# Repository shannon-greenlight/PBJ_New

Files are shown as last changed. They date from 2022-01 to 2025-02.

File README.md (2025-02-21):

# PBJ_New
# This project has been replaced by PBJ_EU_3.

PBJ Project (Proto Board with Jacks) -- For Synthesizer hardware development

https://www.greenfacelabs.com/pbj-eu/

This project provides the KiCAD files used to fab PBJ synthesizer development breadboards.
It requires the KiCAD libraries found at: https://github.com/shannon-greenlight/KiCAD

It also requires the Digi-Key footprint and symbol libraries available at: https://www.digikey.com/en/resources/design-tools/kicad

Add these paths to the symbol libraries:

dk_Sockets-for-ICs-Transistors	.../KiCAD/digikey-symbols/dk_Sockets-for-ICs-Transistors.lib		

dk_Rectangular-Connectors-Headers-Male-Pins	.../KiCAD/digikey-symbols/dk_Rectangular-Connectors-Headers-Male-Pins.lib		

dk_Pushbutton-Switches	.../KiCAD/digikey-symbols/dk_Pushbutton-Switches.lib

greenface-symbols	...\KiCAD\greenface-symbols.lib		

Add these paths to the footprint libraries:

digikey-footprints	.../KiCAD/digikey-footprints.pretty		

panel	...\KiCAD\panel.pretty		

sputterizer	...\KiCAD\sputterizer.pretty		

The Excel file pbj_eu.xlsx can be uploaded directly to Digi-Key to order parts.

Currently, only the PBJ EU is available. But a standalone version, the PBJ Solo, is in the wings.

Note: If you don't have KiCAD and just want to make the PBJ, you can send the Gerber files to fab and use the Excel file to buy the parts. 
The jpegs of the EU in use (EU_inuse.jpg) and of the schematic (PBJ_EU/pbj_eu.jpg) can be used for reference.

PBJ EU Features

800 point solderless proto board

4 switched 3.5mm jacks

Wiring connector interfaces jacks and power to proto board

LED monitors for each jack. Red indicates positive voltage present. Blue indicates negative.

Test point per jack gives convenient access for scope/meter probes.

2 Large Ground connection points are excellent for attaching alligator clips

2 MULT switches connect jack 1 to 2 or jack 3 to 4.

Tip and Switch signals are routed from the jacks to the wiring connector.

+/- 12V and +5V power are routed to the wiring connector.

Power is switched.

Power indicator shows presence of +5V.

10 pin EU power output connector can be used to power off-rack modules.

22 HP wide

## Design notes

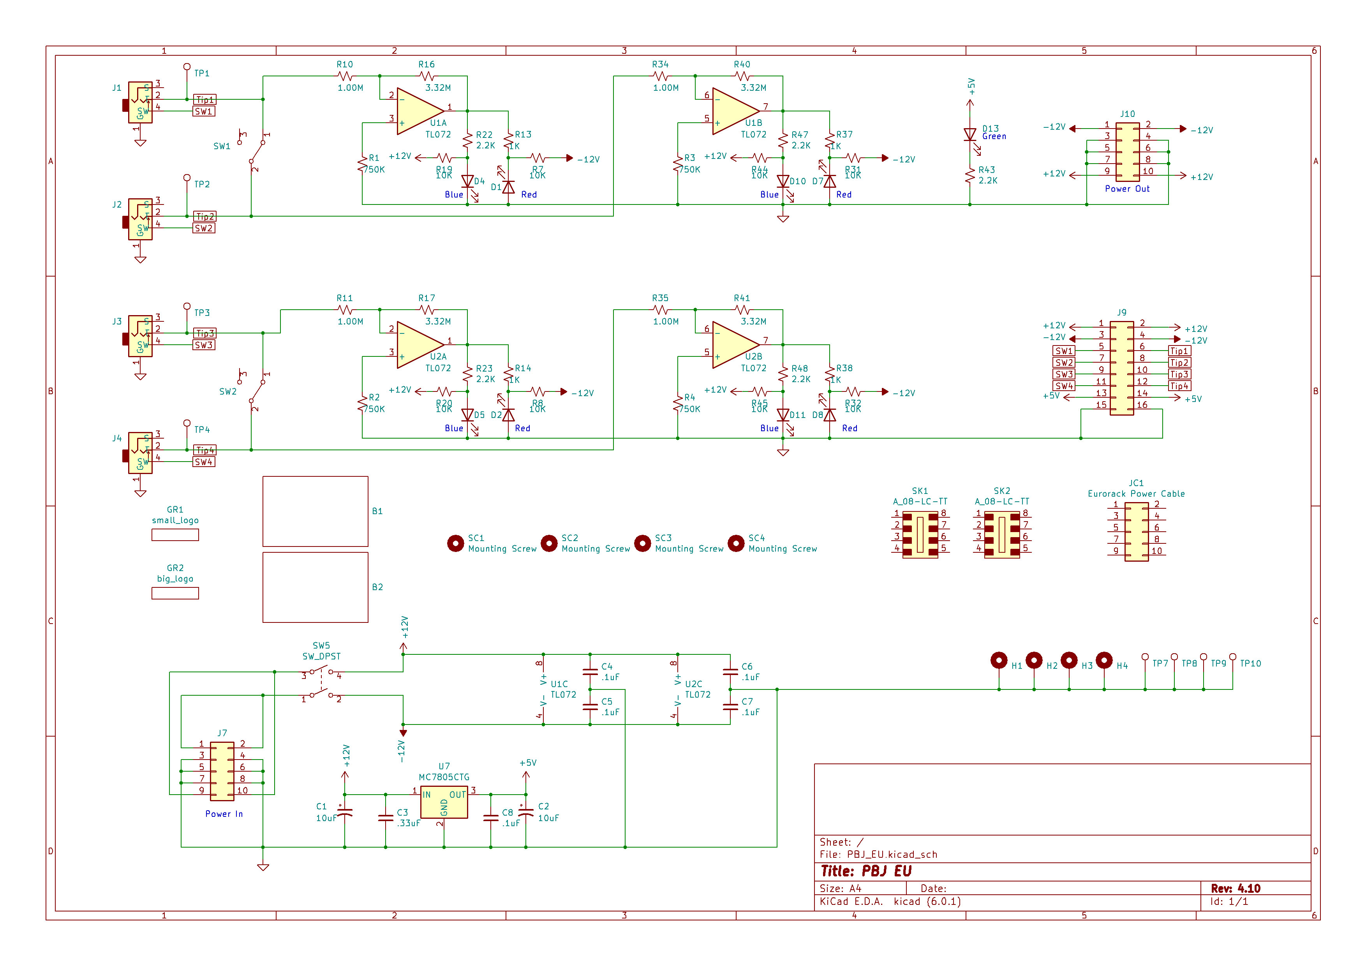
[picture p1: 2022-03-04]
PBJ_EU/pbj_eu.jpg

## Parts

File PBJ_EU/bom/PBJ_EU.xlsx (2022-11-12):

Reference | Quantity | Value | Digi-Key Part
B1 B2 | 2 | Breadboard_400 | 1286-1185-ND
C1 C4 C5 C12 | 4 | 10uF | 478-7366-1-ND
C2 C8 | 2 | .33uF | 445-180638-1-ND
C3 C6 C7 C9 C10 C11 | 6 | .1uF | 478-3188-ND
D1 D3 D5 D7 | 4 | RED LED | 732-5005-ND
D2 D4 D6 D8 | 4 | BLUE LED | 732-11401-ND
D9 | 1 | GREEN LED | 732-5008-ND
J1 J2 J3 J4 | 4 | Molex_47257 | WM17366-ND
J5 J7 | 2 | Conn_02x05_Odd_Even | S2011EC-05-ND
J6 | 1 | Conn_02x08_Odd_Even_Female | S7111-ND
JC1 | 1 | Eurorack Power Cable | H3CCS-1018G-ND
R1 R2 R3 R4 | 4 | 1K | CF14JT1K00CT-ND
R5 | 1 | 2.2K | CF14JT2K20CT-ND
SC1 SC2 SC3 SC4 | 4 | Mounting Screw | 335-1156-ND
SK1 SK2 | 2 | A_08-LC-TT | AE9986-ND
SW1 SW2 | 2 | SW_SPDT | CKN10397-ND
SW3 | 1 | SW_DPST | CKN9891-ND
TP1 TP2 TP3 TP4 TP5 TP6 TP7 TP8 | 8 | TestPoint | 36-5006-ND
U1 U2 | 2 | TL072 | 296-14997-5-ND
U3 | 1 | MC7805CTG | MC7805CTGOS-ND
U4 | 1 | MIC29150-3.3WT | 576-1104-ND

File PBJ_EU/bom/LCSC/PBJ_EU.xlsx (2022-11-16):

Reference | Quantity | Value | Footprint | LCSC Part #
C1 C5 | 2 | 10uF | Capacitor_THT:CP_Radial_D5.0mm_P2.00mm | C88726
C13 C14 C15 C16 | 4 | 10nF | Capacitor_THT:C_Rect_L7.0mm_W2.0mm_P5.00mm | C1710
C2 C6 C7 C8 C10 C11 | 6 | .1uF | Capacitor_THT:C_Rect_L7.0mm_W2.0mm_P5.00mm | C84772
C4 C12 | 2 | 22uF | Capacitor_THT:CP_Radial_D5.0mm_P2.00mm | C43346
D18 D19 D20 D21 | 4 | SB120 | Diode_THT:D_DO-41_SOD81_P7.62mm_Horizontal | C174003
J5 J7 | 2 | Conn_02x05_Odd_Even | Connector_PinHeader_2.54mm:PinHeader_2x05_P2.54mm_Vertical | C492422
R1 R2 R3 R4 R5 R6 R7 R8 R9 R14 R15 R16 | 12 | 2.2K | Resistor_THT:R_Axial_DIN0207_L6.3mm_D2.5mm_P10.16mm_Horizontal | C120063
R10 R11 R12 R13 | 4 | 1M | Resistor_THT:R_Axial_DIN0207_L6.3mm_D2.5mm_P10.16mm_Horizontal | C433776
R17 R18 | 2 | 620 | Resistor_THT:R_Axial_DIN0207_L6.3mm_D2.5mm_P10.16mm_Horizontal | C713992
RV1 RV2 | 2 | 5K | Potentiometer_THT:Potentiometer_Bourns_3296W_Vertical | C60620
SK1 SK2 | 2 | A_08-LC-TT | Package_DIP:DIP-8_W7.62mm_Socket_LongPads | C72124
TP1 TP2 TP3 TP4 TP5 TP6 TP7 TP8 | 8 | TestPoint | TestPoint:TestPoint_Keystone_5005-5009_Compact | C238123
U1 U2 | 2 | TL072 | Package_DIP:DIP-8_W7.62mm_Socket_LongPads | C72124
U3 U4 | 2 | LM317_TO-220 | Package_TO_SOT_THT:TO-220-3_Vertical | C14502

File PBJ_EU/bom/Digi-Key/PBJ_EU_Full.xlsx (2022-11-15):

Reference | Quantity | Value | Digi-Key Part | Other
B1 B2 | 2 | Breadboard_400 | 1286-1185-ND
C1 C5 | 2 | 10uF | P124234CT-ND
C13 C14 C15 C16 | 4 | 10nF | BC2662CT-ND
C2 C6 C7 C8 C10 C11 | 6 | .1uF | 478-3188-ND
C4 C12 | 2 | 22uF | P15374CT-ND
D18 D19 D20 D21 | 4 | SB120 | 112-SB120-E3/54CT-ND
J1 J2 J3 J4 | 4 | Molex_47257 | WM17366-ND
J5 J7 | 2 | Conn_02x05_Odd_Even | S2011EC-05-ND
J6 | 1 | Conn_02x08_Odd_Even_Female | S7111-ND
JC1 | 1 | Eurorack Power Cable | H3CCS-1018G-ND
R1 R2 R3 R4 R5 R6 R7 R8 R9 R14 R15 R16 | 12 | 2.2K | CF14JT2K20CT-ND
R10 R11 R12 R13 | 4 | 1M | CF14JT1M00CT-ND
R17 R18 | 2 | 620 | S620CACT-ND
RV1 RV2 | 2 | 5K | 3296W-502LF-ND
SC1 SC2 SC3 SC4 | 4 | Mounting Screw | 335-1156-ND
SK1 SK2 | 2 | A_08-LC-TT | AE9986-ND
SW1 SW2 SW4 | 3 | SW_SPDT | CKN10397-ND
SW3 | 1 | SW_DPST | CKN9891-ND
TP1 TP2 TP3 TP4 TP5 TP6 TP7 TP8 | 8 | TestPoint | 36-5006-ND
U1 U2 | 2 | TL072 | 296-1775-5-ND
U3 U4 | 2 | LM317_TO-220 | 497-19621-ND

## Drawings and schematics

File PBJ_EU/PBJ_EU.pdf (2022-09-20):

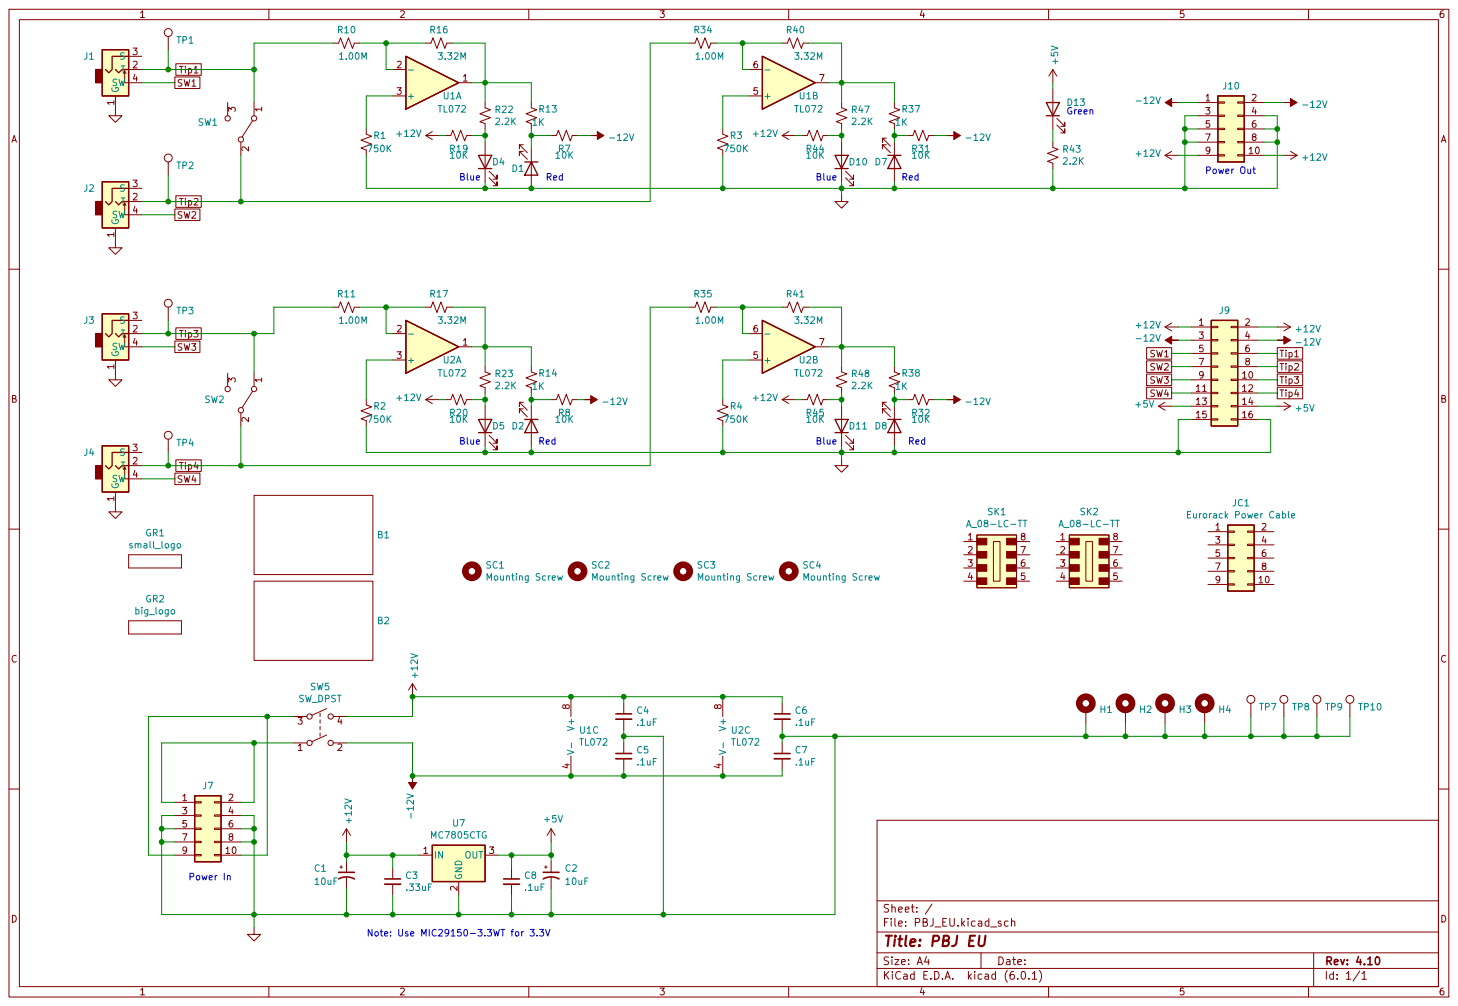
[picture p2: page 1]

Blue Blue Note: Use MIC29150-3.3WT for 3.3V

Id: 1/1 Title: PBJ EU

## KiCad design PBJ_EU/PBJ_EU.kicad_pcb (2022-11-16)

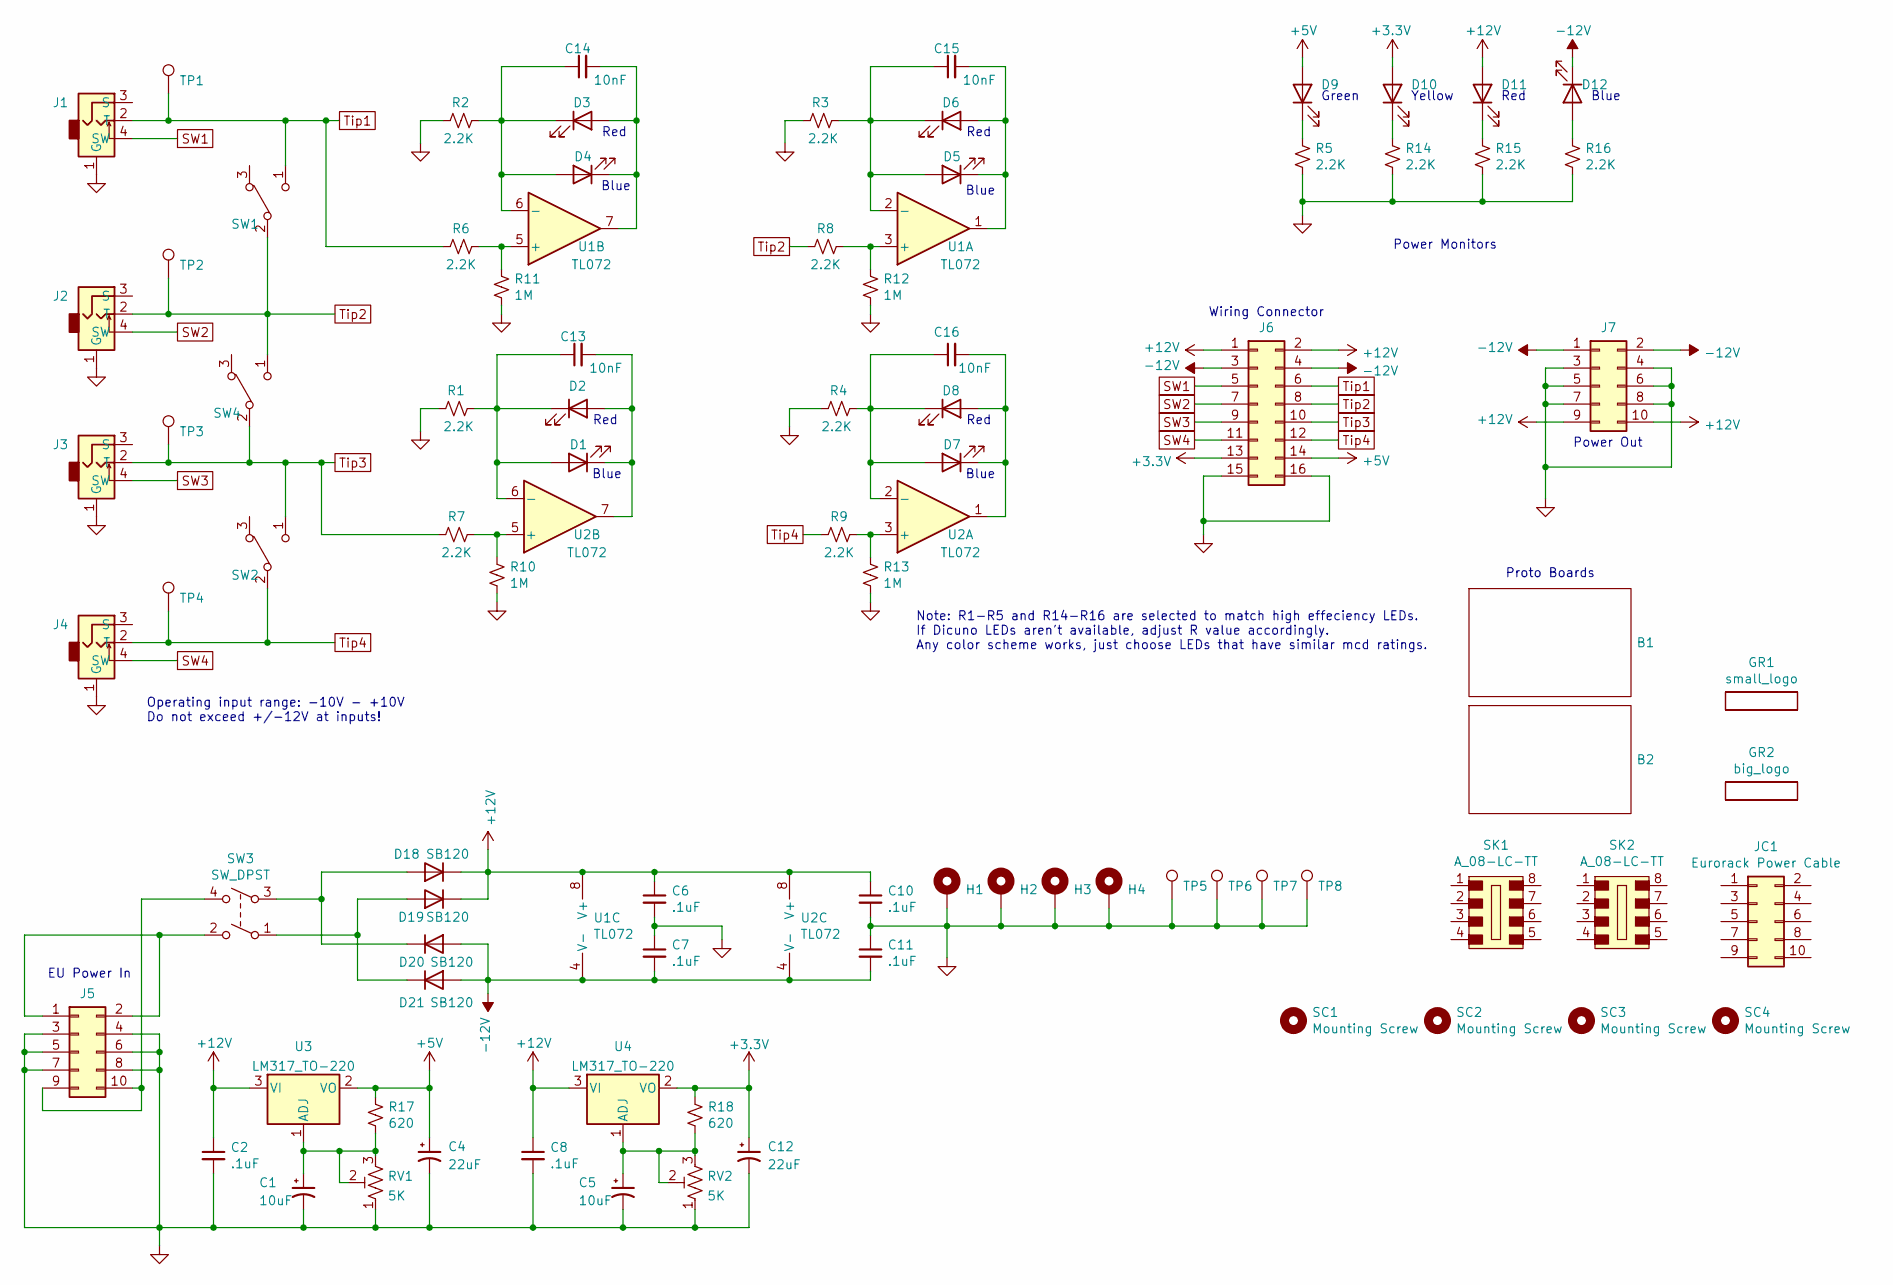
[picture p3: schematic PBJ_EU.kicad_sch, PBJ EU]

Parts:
B1, B2: Breadboard_400; Proto_400; Digi-Key Part 1286-1185-ND
C1, C5: 10uF; CP_Radial_D5.0mm_P2.00mm; Digi-Key Part P124234CT-ND
C2, C6, C7, C8, C10, C11: .1uF; C_Rect_L7.0mm_W2.0mm_P5.00mm; Digi-Key Part 478-3188-ND
C4, C12: 22uF; CP_Radial_D5.0mm_P2.00mm; Digi-Key Part P15374CT-ND
C13, C14, C15, C16: 10nF; C_Rect_L7.0mm_W2.0mm_P5.00mm; Digi-Key Part BC2662CT-ND
D1, D4, D5, D7, D12: BLUE LED; LED_D3.0mm
D2, D3, D6, D8, D11: RED LED; LED_D3.0mm
D9: GREEN LED; LED_D3.0mm
D10: YELLOW LED; LED_D3.0mm
D18, D19, D20, D21: SB120; D_DO-41_SOD81_P7.62mm_Horizontal; Digi-Key Part 112-SB120-E3/54CT-ND
GR1: small_logo; small_face
GR2: big_logo; logo_black
H1, H2, H3, H4: MountingHole_Pad; MountingHole_3.2mm_M3_SmPad
J1, J2, J3, J4: Molex_47257; Molex-0472570001; Digi-Key Part WM17366-ND
J5, J7: Conn_02x05_Odd_Even; PinHeader_2x05_P2.54mm_Vertical; Digi-Key Part S2011EC-05-ND
J6: Conn_02x08_Odd_Even_Female; PinHeader_2x08_P2.54mm_Vertical; Digi-Key Part S7111-ND
JC1: Eurorack Power Cable; Digi-Key Part H3CCS-1018G-ND
R1, R2, R3, R4, R5, R6, R7, R8, R9, R14, R15, R16: 2.2K; R_Axial_DIN0207_L6.3mm_D2.5mm_P10.16mm_Horizontal; Digi-Key Part CF14JT2K20CT-ND
R10, R11, R12, R13: 1M; R_Axial_DIN0207_L6.3mm_D2.5mm_P10.16mm_Horizontal; Digi-Key Part CF14JT1M00CT-ND
R17, R18: 620; R_Axial_DIN0207_L6.3mm_D2.5mm_P10.16mm_Horizontal; Digi-Key Part S620CACT-ND
RV1, RV2: 5K; Potentiometer_Bourns_3296W_Vertical; Digi-Key Part 3296W-502LF-ND
SC1, SC2, SC3, SC4: Mounting Screw; Digi-Key Part 335-1156-ND
SK1, SK2: A_08-LC-TT; DIP-8_W7.62mm_Socket_LongPads; Digi-Key Part AE9986-ND
SW1, SW2, SW4: SW_SPDT; SW_Slide_1P2T_CK_OS102011MS2Q; Digi-Key Part CKN10397-ND
SW3: SW_DPST; S202031MS02Q; Digi-Key Part CKN9891-ND
TP1, TP2, TP3, TP4: TestPoint; TestPoint_Keystone_5005-5009_Compact; Digi-Key Part 36-5006-ND
TP5, TP6, TP7, TP8: TestPoint; TestPoint_Keystone_5005-5009_Compact
U1, U2: TL072; DIP-8_W7.62mm_Socket_LongPads; Digi-Key Part 296-1775-5-ND
U3, U4: LM317_TO-220; TO-220-3_Vertical; Digi-Key Part 497-19621-ND

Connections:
+3V3: C12.1, D10.2 (A), J6.13, R18.1, U4.2 (VO)
+5V: C4.1, D9.2 (A), J6.14, R17.1, U3.2 (VO)
+12V: C2.1, C6.1, C8.1, C10.1, D11.2 (A), D18.1 (K), D19.1 (K), J6.1, J6.2, J7.9, J7.10, U1.8 (V+), U2.8 (V+), U3.3 (VI), U4.3 (VI)
-12V: C7.2, C11.2, D12.1 (K), D20.2 (A), D21.2 (A), J6.3, J6.4, J7.1, J7.2, U1.4 (V-), U2.4 (V-)
GND: C1.2, C2.2, C4.2, C5.2, C6.2, C7.1, C8.2, C10.2, C11.1, C12.2, H1.1, H2.1, H3.1, H4.1, J1.1 (G), J2.1 (G), J3.1 (G), J4.1 (G), J5.3, J5.4, J5.5, J5.6, J5.7, J5.8, J6.15, J6.16, J7.3, J7.4, J7.5, J7.6, J7.7, J7.8, R1.1, R2.1, R3.1, R4.1, R5.2, R10.2, R11.2, R12.2, R13.2, R14.2, R15.2, R16.2, RV1.1, RV2.1, TP5.1, TP6.1, TP7.1, TP8.1
unnamed: C1.1, R17.2, RV1.2, RV1.3, U3.1 (ADJ)
unnamed: C5.1, R18.2, RV2.2, RV2.3, U4.1 (ADJ)
unnamed: C13.1, D1.2 (A), D2.1 (K), R1.2, U2.6 (-)
unnamed: C13.2, D1.1 (K), D2.2 (A), U2.7
unnamed: C14.1, D3.1 (K), D4.2 (A), R2.2, U1.6 (-)
unnamed: C14.2, D3.2 (A), D4.1 (K), U1.7
unnamed: C15.1, D5.2 (A), D6.1 (K), R3.2, U1.2 (-)
unnamed: C15.2, D5.1 (K), D6.2 (A), U1.1
unnamed: C16.1, D7.2 (A), D8.1 (K), R4.2, U2.2 (-)
unnamed: C16.2, D7.1 (K), D8.2 (A), U2.1
unnamed: D9.1 (K), R5.1
unnamed: D10.1 (K), R14.1
unnamed: D11.1 (K), R15.1
unnamed: D12.2 (A), R16.1
unnamed: D18.2 (A), D20.1 (K), SW3.3
unnamed: D19.2 (A), D21.1 (K), SW3.1
unnamed: J5.1, J5.2, SW3.2
unnamed: J5.9, J5.10, SW3.4
unnamed: R7.1, R10.1, U2.5 (+)
unnamed: R6.1, R11.1, U1.5 (+)
unnamed: R8.1, R12.1, U1.3 (+)
unnamed: R9.1, R13.1, U2.3 (+)
SW1: J1.4 (SW), J6.5
SW2: J2.4 (SW), J6.7
SW3: J3.4 (SW), J6.9
SW4: J4.4 (SW), J6.11
Tip1: J1.2 (T), J6.6, R6.2, SW1.1 (A), TP1.1
Tip2: J2.2 (T), J6.8, R8.2, SW1.2 (B), SW4.1 (A), TP2.1
Tip3: J3.2 (T), J6.10, R7.2, SW2.1 (A), SW4.2 (B), TP3.1
Tip4: J4.2 (T), J6.12, R9.2, SW2.2 (B), TP4.1

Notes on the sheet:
EU Power In
Blue
Proto Boards
Red
Wiring Connector
Yellow
Power Monitors
Operating input range: -10V - +10V Do not exceed +/-12V at inputs!
Note: R1-R5 and R14-R16 are selected to match high effeciency LEDs. If Dicuno LEDs aren't available, adjust R value accordingly. Any color scheme works, just choose LEDs that have similar mcd ratings.
Power Out
Green

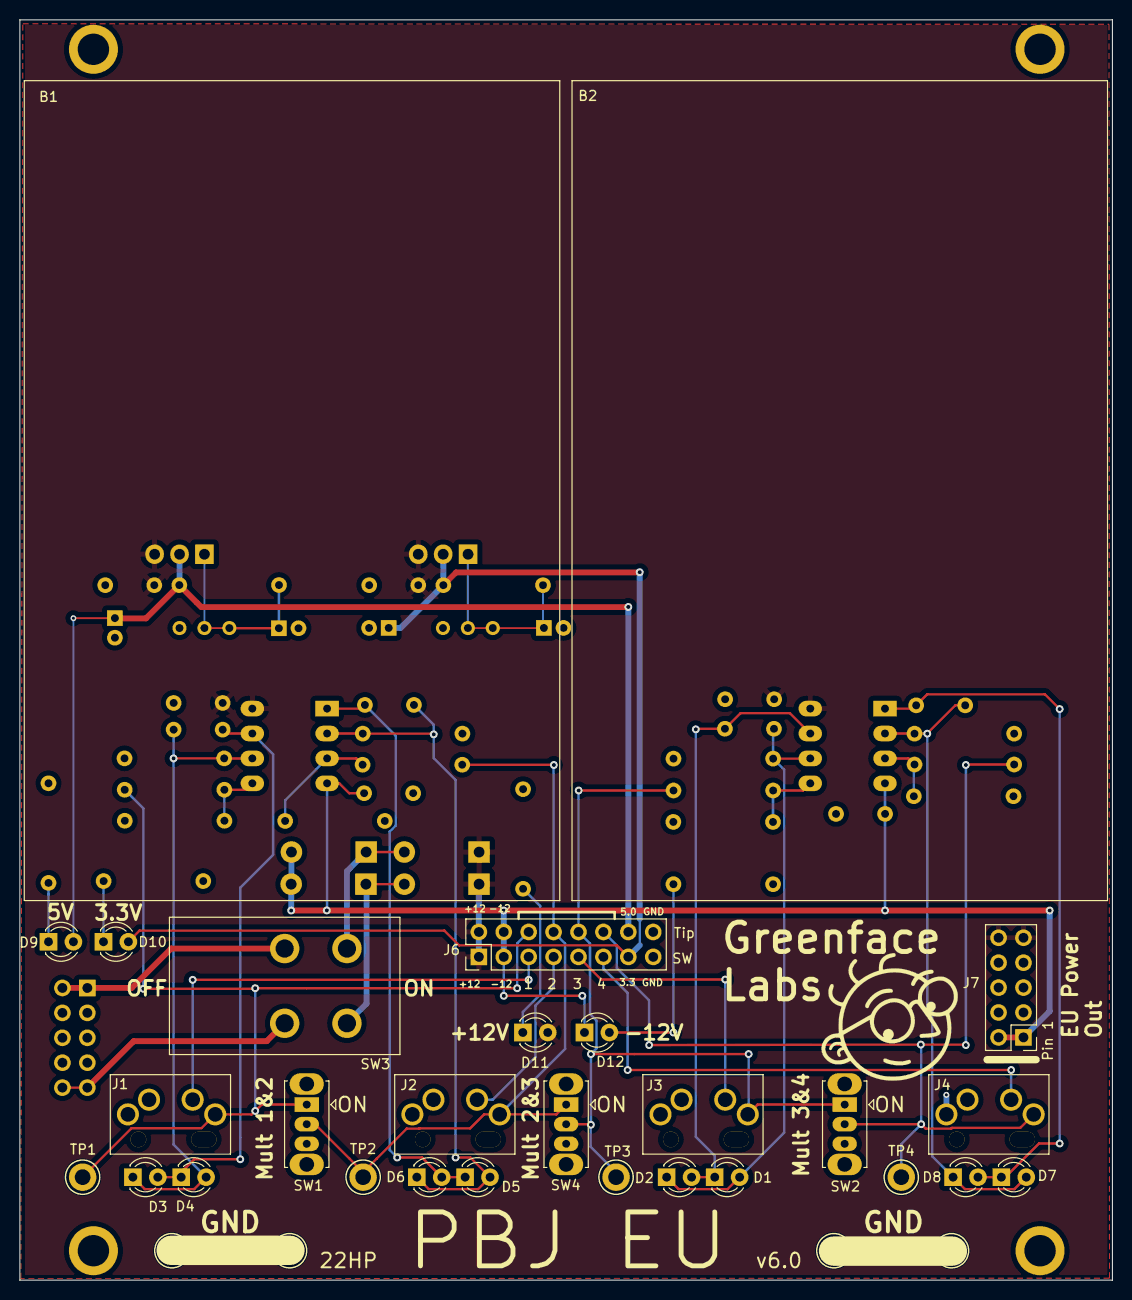
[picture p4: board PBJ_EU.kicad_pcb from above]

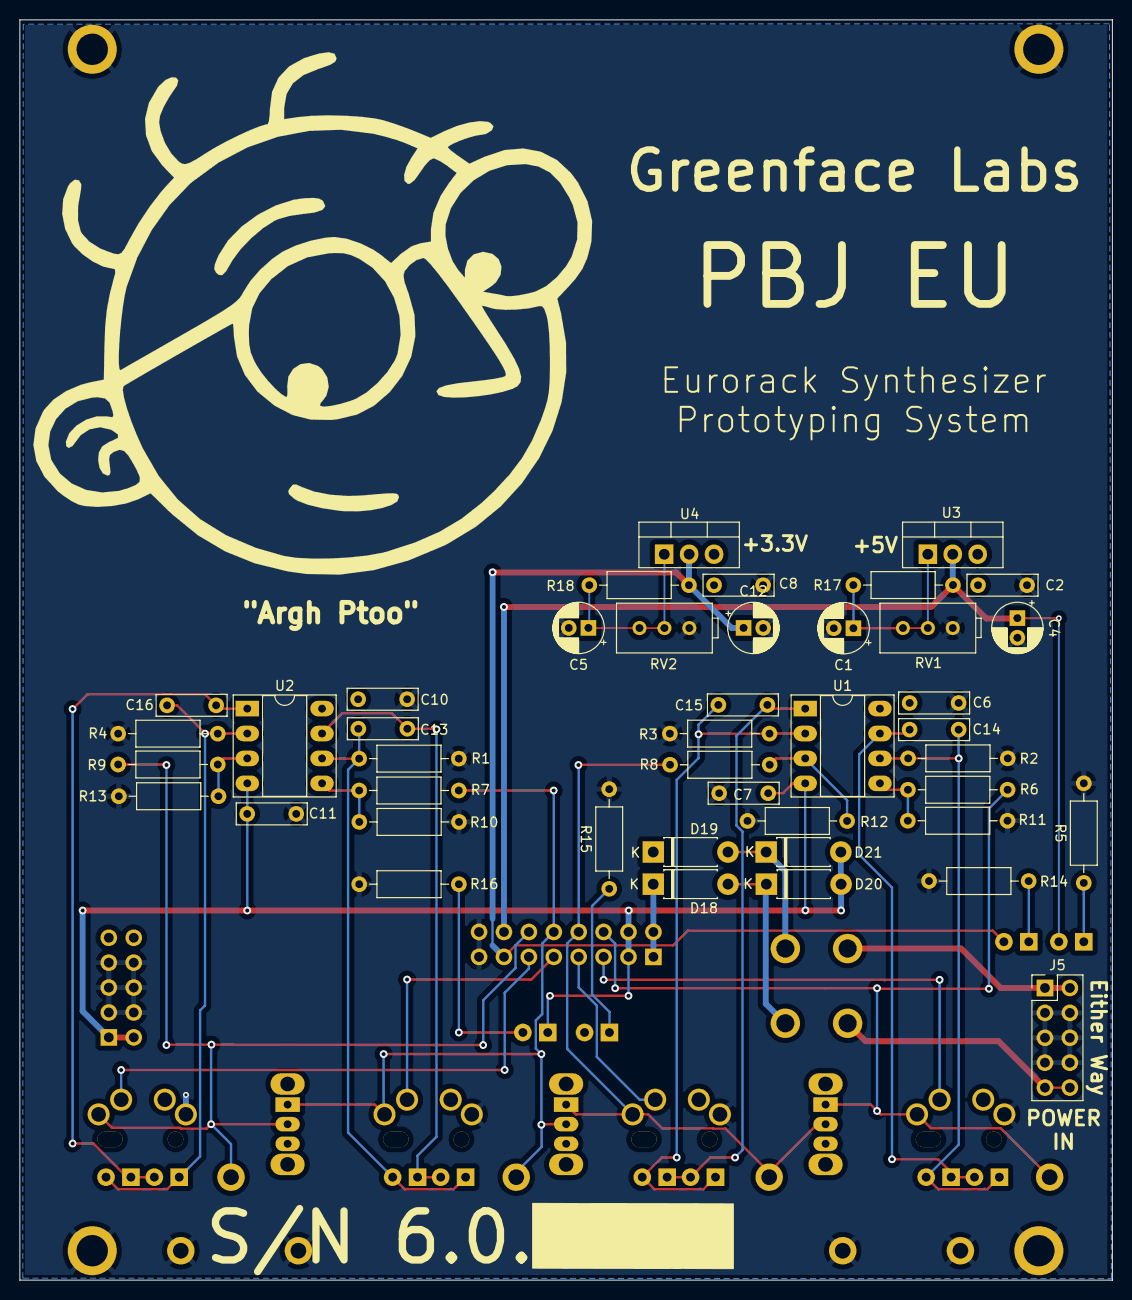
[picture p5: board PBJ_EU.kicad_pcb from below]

Board: 2 copper layers, 111.4 x 128.5 mm, 81 parts (44 on the bottom side), 35 nets.

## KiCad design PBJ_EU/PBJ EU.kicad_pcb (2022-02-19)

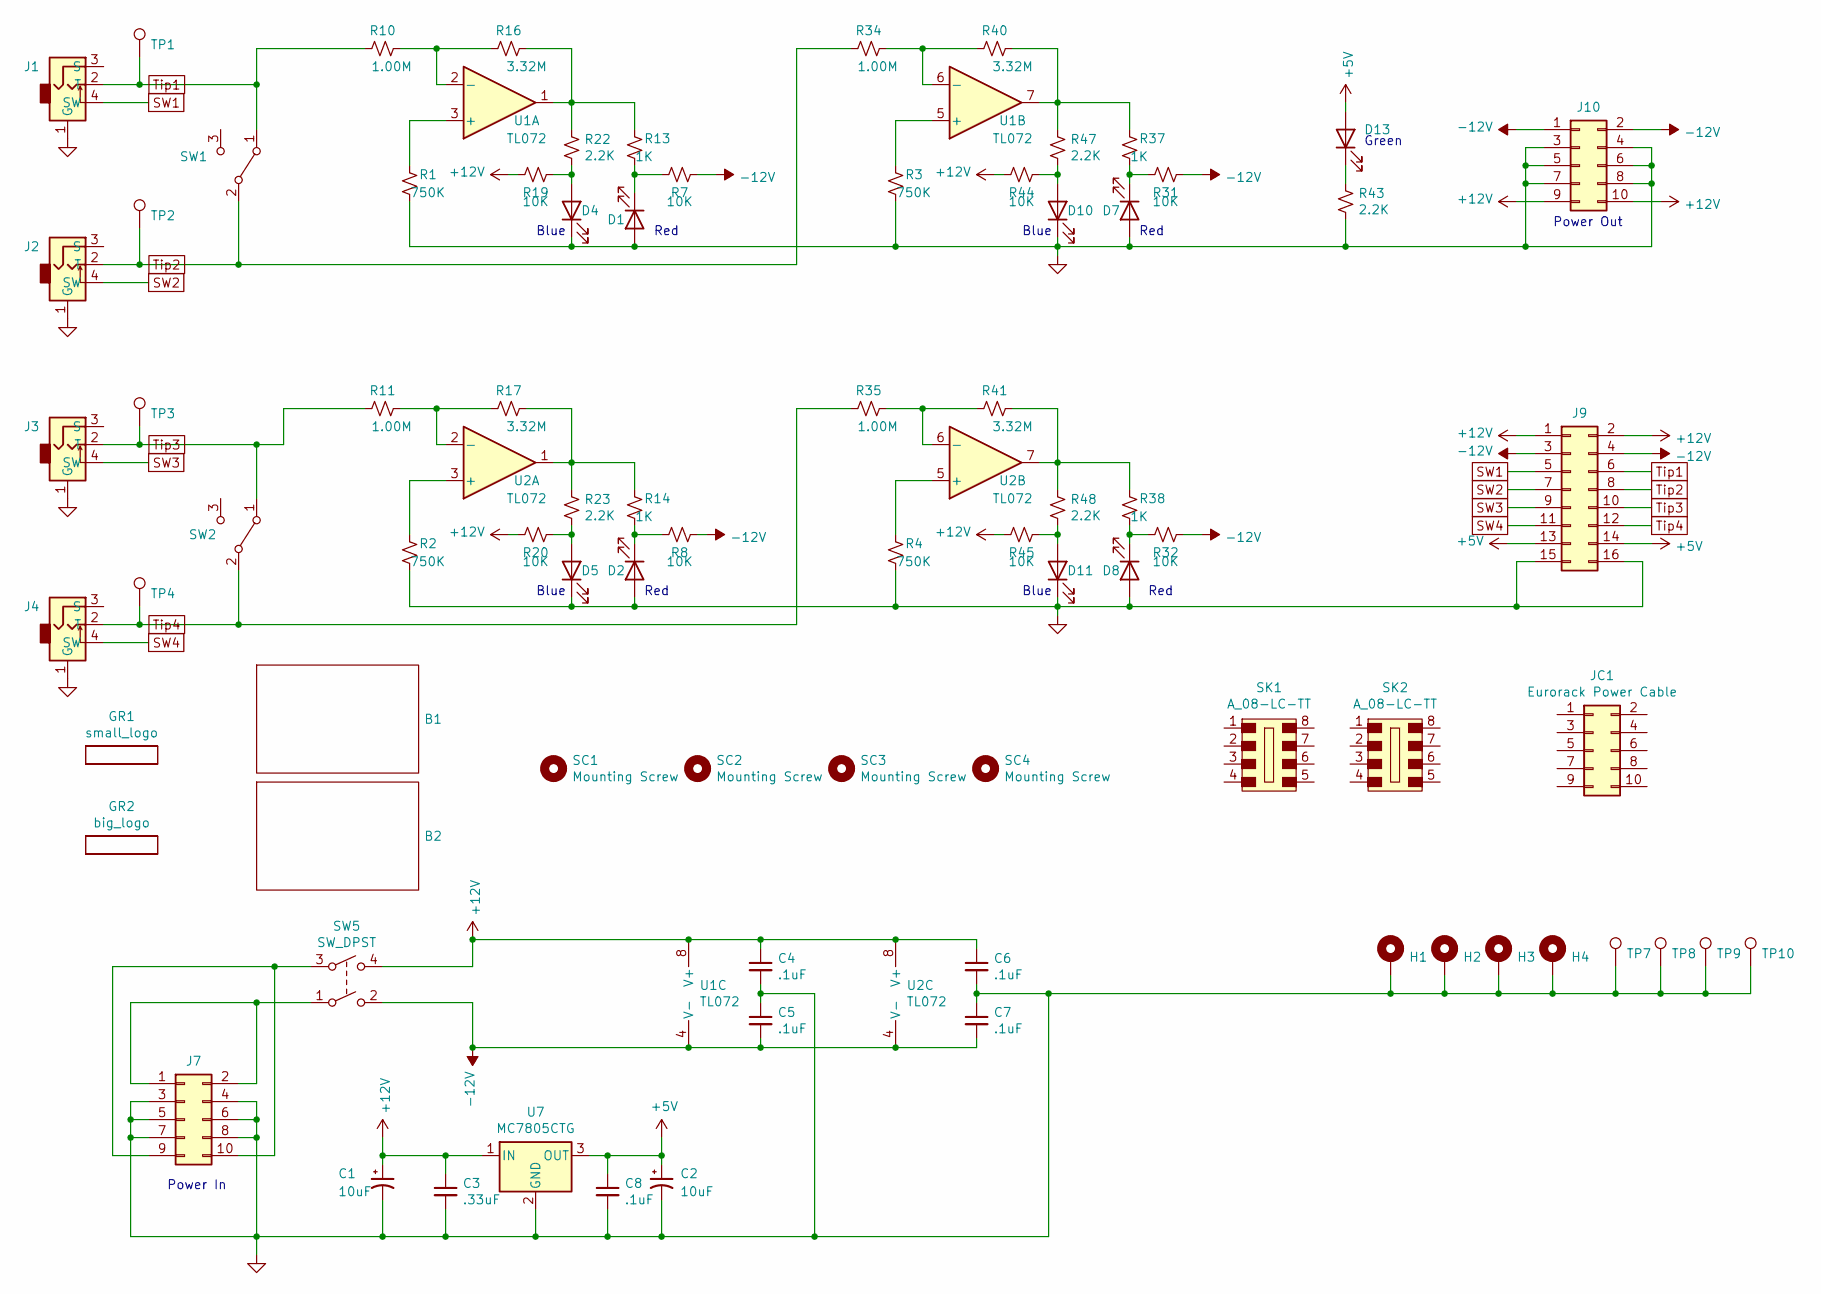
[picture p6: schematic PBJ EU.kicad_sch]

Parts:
B1, B2: Breadboard_400; Proto_400; Digi-Key Part 1286-1185-ND
C1, C2: 10uF; CP_Radial_Tantal_D5.0mm_P5.00mm; Digi-Key Part 478-7366-1-ND
C3: .33uF; C_Rect_L7.0mm_W2.0mm_P5.00mm; Digi-Key Part 445-180638-1-ND
C4, C5, C6, C7, C8: .1uF; C_Rect_L7.0mm_W2.0mm_P5.00mm; Digi-Key Part 478-3188-ND
D1, D2, D7, D8: RED LED; LED_D3.0mm; Digi-Key Part 732-5005-ND
D4, D5, D10, D11: BLUE LED; LED_D3.0mm; Digi-Key Part 732-11401-ND
D13: GREEN LED; LED_D3.0mm; Digi-Key Part 732-5008-ND
GR1: small_logo; small_face
GR2: big_logo; logo_black
H1, H2, H3, H4: MountingHole_Pad; MountingHole_3.2mm_M3_SmPad
J1, J2, J3, J4: Molex_47257; Molex-0472570001; Digi-Key Part WM17366-ND
J7, J10: Conn_02x05_Odd_Even; PinHeader_2x05_P2.54mm_Vertical; Digi-Key Part S2011EC-05-ND
J9: Conn_02x08_Odd_Even_Female; PinHeader_2x08_P2.54mm_Vertical; Digi-Key Part S7111-ND
JC1: Eurorack Power Cable; Digi-Key Part H3CCS-1018G-ND
R1, R2, R3, R4: 750K; R_Axial_DIN0207_L6.3mm_D2.5mm_P10.16mm_Horizontal; Digi-Key Part S750KQCT-ND
R7, R8, R19, R20, R31, R32, R44, R45: 10K; R_Axial_DIN0207_L6.3mm_D2.5mm_P10.16mm_Horizontal; Digi-Key Part CF14JT10K0CT-ND
R10, R11, R34, R35: 1.00M; R_Axial_DIN0207_L6.3mm_D2.5mm_P10.16mm_Horizontal; Digi-Key Part RNF14FTD1M00CT-ND
R13, R14, R37, R38: 1K; R_Axial_DIN0207_L6.3mm_D2.5mm_P10.16mm_Horizontal; Digi-Key Part CF14JT1K00CT-ND
R16, R17, R40, R41: 3.32M; R_Axial_DIN0207_L6.3mm_D2.5mm_P10.16mm_Horizontal; Digi-Key Part RNF14FTD3M32CT-ND
R22, R23, R43, R47, R48: 2.2K; R_Axial_DIN0207_L6.3mm_D2.5mm_P10.16mm_Horizontal; Digi-Key Part CF14JT2K20CT-ND
SC1, SC2, SC3, SC4: Mounting Screw; Digi-Key Part 335-1156-ND
SK1, SK2: A_08-LC-TT; Digi-Key Part AE9986-ND
SW1, SW2: SW_SPDT; SW_Slide_1P2T_CK_OS102011MS2Q; Digi-Key Part CKN10397-ND
SW5: SW_DPST; S202031MS02Q; Digi-Key Part CKN9891-ND
TP1, TP2, TP3, TP4, TP7, TP8, TP9, TP10: TestPoint; TestPoint_Keystone_5005-5009_Compact; Digi-Key Part 36-5006-ND
U1: TL072
U2: TL072; DIP-8_W7.62mm; Digi-Key Part 296-14997-5-ND‎
U7: MC7805CTG; TO-220-3_Vertical; Digi-Key Part MC7805CTGOS-ND

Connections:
+5V: C2.1, C8.1, D13.2 (A), J9.13, J9.14, U7.3 (OUT)
+12V: C1.1, C3.1, C4.1, C6.1, J9.1, J9.2, J10.9, J10.10, R19.1, R20.1, R44.1, R45.1, SW5.4, U1.8 (V+), U2.8 (V+), U7.1 (IN)
-12V: C5.2, C7.2, J9.3, J9.4, J10.1, J10.2, R7.2, R8.2, R31.2, R32.2, SW5.2, U1.4 (V-), U2.4 (V-)
GND: C1.2, C2.2, C3.2, C4.2, C5.1, C6.2, C7.1, C8.2, D1.2 (A), D2.2 (A), D4.1 (K), D5.1 (K), D7.2 (A), D8.2 (A), D10.1 (K), D11.1 (K), H1.1, H2.1, H3.1, H4.1, J1.1 (G), J2.1 (G), J3.1 (G), J4.1 (G), J7.3, J7.4, J7.5, J7.6, J7.7, J7.8, J9.15, J9.16, J10.3, J10.4, J10.5, J10.6, J10.7, J10.8, R1.2, R2.2, R3.2, R4.2, R43.2, TP7.1, TP8.1, TP9.1, TP10.1, U7.2 (GND)
unnamed: D1.1 (K), R7.1, R13.2
unnamed: D2.1 (K), R8.1, R14.2
unnamed: D4.2 (A), R19.2, R22.2
unnamed: D5.2 (A), R20.2, R23.2
unnamed: D7.1 (K), R31.1, R37.2
unnamed: D8.1 (K), R32.1, R38.2
unnamed: D10.2 (A), R44.2, R47.2
unnamed: D11.2 (A), R45.2, R48.2
unnamed: D13.1 (K), R43.1
unnamed: J7.1, J7.2, SW5.1
unnamed: J7.9, J7.10, SW5.3
unnamed: R1.1, U1.3 (+)
unnamed: R2.1, U2.3 (+)
unnamed: R3.1, U1.5 (+)
unnamed: R4.1, U2.5 (+)
unnamed: R10.2, R16.1, U1.2 (-)
unnamed: R11.2, R17.1, U2.2 (-)
unnamed: R13.1, R16.2, R22.1, U1.1
unnamed: R14.1, R17.2, R23.1, U2.1
unnamed: R34.2, R40.1, U1.6 (-)
unnamed: R35.2, R41.1, U2.6 (-)
unnamed: R37.1, R40.2, R47.1, U1.7
unnamed: R38.1, R41.2, R48.1, U2.7
SW1: J1.4 (SW), J9.5
SW2: J2.4 (SW), J9.7
SW3: J3.4 (SW), J9.9
SW4: J4.4 (SW), J9.11
Tip1: J1.2 (T), J9.6, R10.1, SW1.1 (A), TP1.1
Tip2: J2.2 (T), J9.8, R34.1, SW1.2 (B), TP2.1
Tip3: J3.2 (T), J9.10, R11.1, SW2.1 (A), TP3.1
Tip4: J4.2 (T), J9.12, R35.1, SW2.2 (B), TP4.1

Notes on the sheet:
Blue
Power In
Red
Power Out
Green

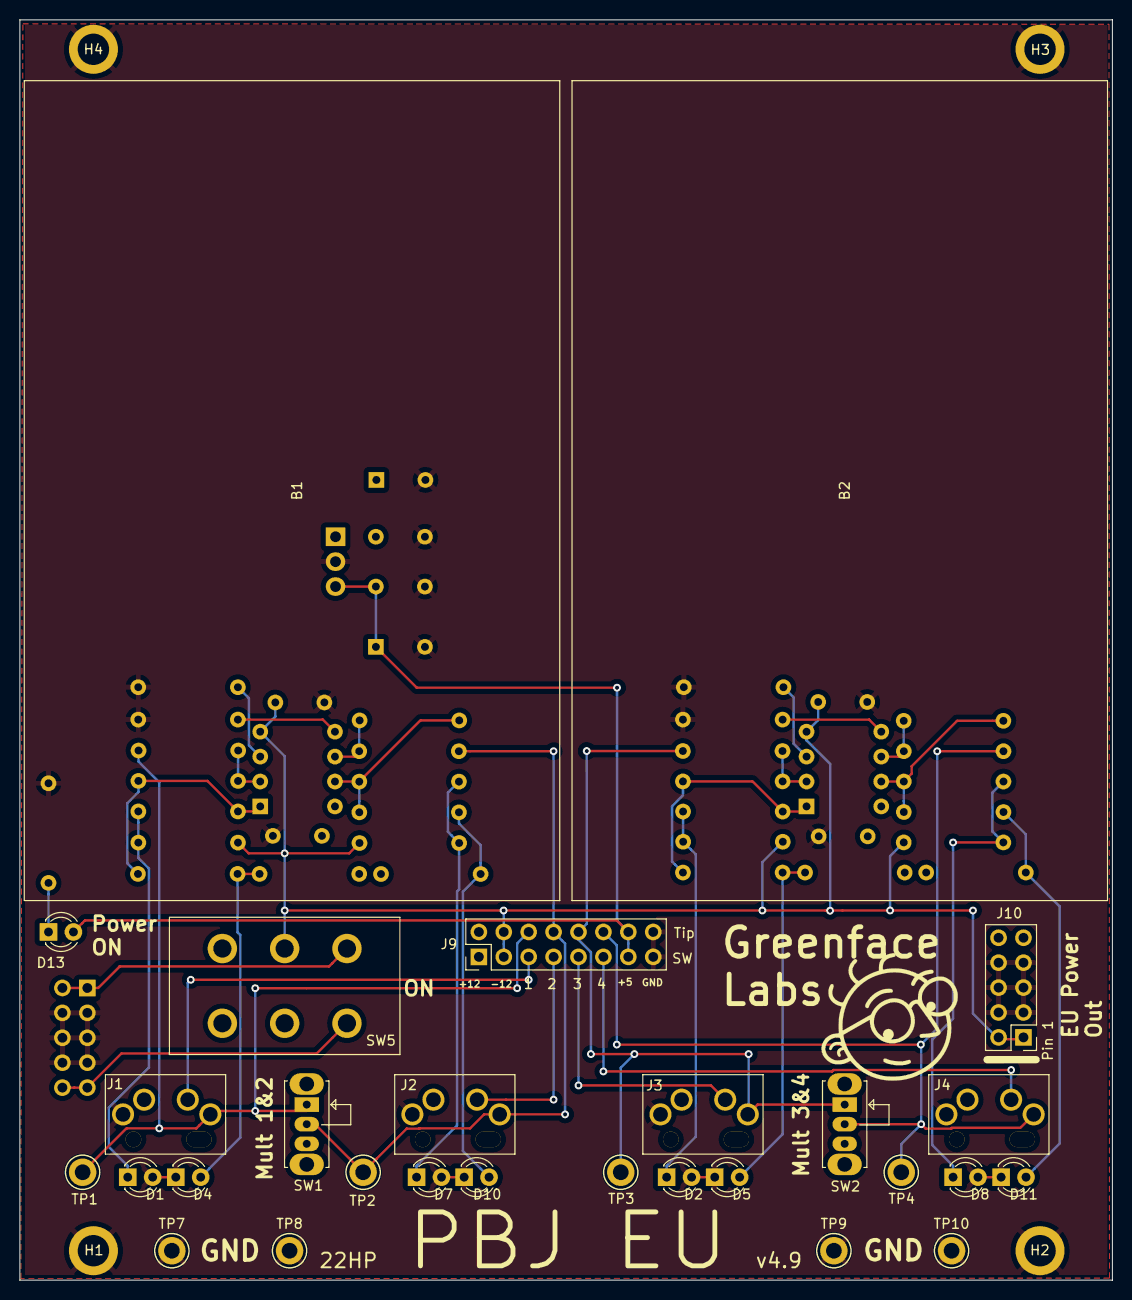
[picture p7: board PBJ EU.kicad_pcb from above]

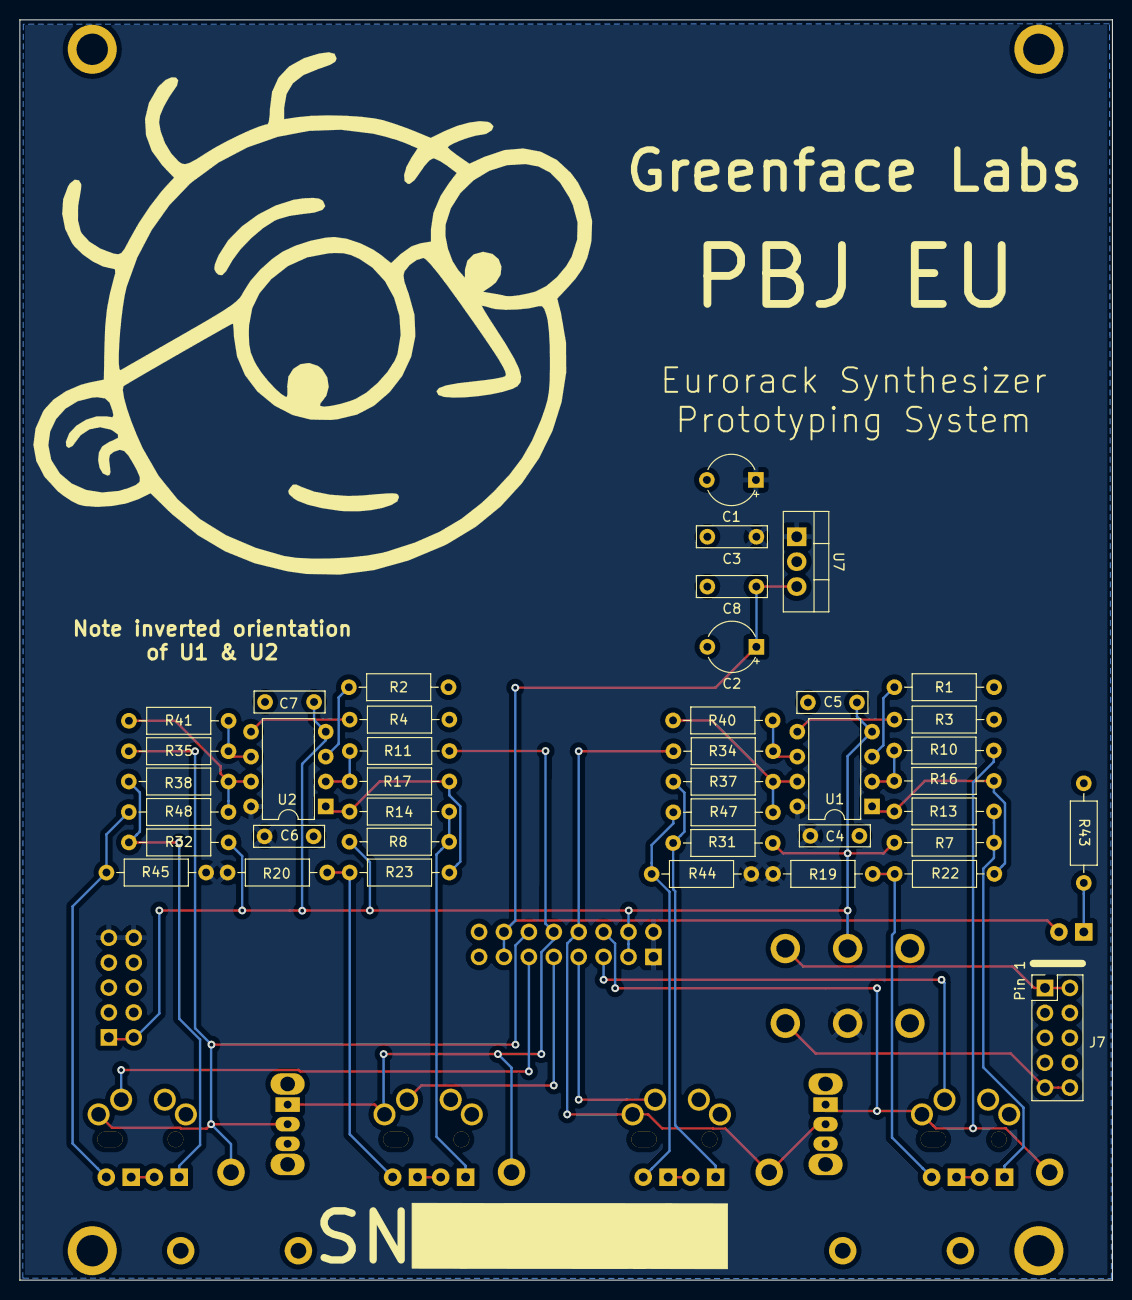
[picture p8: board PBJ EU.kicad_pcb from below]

Board: 2 copper layers, 111.4 x 128.5 mm, 75 parts (42 on the bottom side), 35 nets.

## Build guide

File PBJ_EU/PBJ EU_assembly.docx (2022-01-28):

# PBJ EU Assembly Instructions

The PBJ EU uses components on both sides of the board as well as stacked components to maximize rack space. Because of this, the order of assembly is designed to avoid installing a component that covers the holes of another component.

Because of the density of the circuitry, a conical .8mm tip soldering iron is suggested.

Difficulty: beginner. OK for first build.

1. Install components on back side of the board first. This is most components including op amps, resistors, capacitors and the voltage regulator. Use of sockets for the op amps is recommended.
2. Trim leads so that they are as flush with the front side of the board as possible. This is to avoid shorts to the proto board which is placed on top of this area.
3. Install front-side components. Connectors, jacks LEDs etc.
4. Install proto-boards. They lock together for a tight fit. You can do this before fixing them to the board.
5. That’s all! You’re ready to test.

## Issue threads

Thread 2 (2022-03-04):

Jpegs missing?

rahji, 2022-03-04:
The readme says "The jpegs of the EU in use (EU_inuse.jpg) and of the schematic (PBJ_EU/pbj_eu.jpg) can be used for reference." but I don't see them in the repo. (Thanks for doing this btw - I think every PCB project repo should have images or PDFs of the schematic, PCB, etc and not just EDA/gerber files.

shannon-greenlight, 2022-03-04:
My mistake! I will fix it in the repo. But for now, here is the pdf version.

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

shannon-greenlight, 2022-03-04:
Here’s the jpeg.

Please let me know if you find any other problems.

Thanks!

Shannon

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

rahji, 2022-03-04:
We're the PDF and the JPG supposed to be the same? I thought the JPG was a photo of the board in use. Right now they're both the schematic . Thanks

shannon-greenlight, 2022-03-04:
Hi Rob,

At this point they are supposed to be the same. However, your suggestion is a good one. I will see if I can develop a consistent approach for all of my products.

In the meantime, you can see a picture of the PBJ EU in use on the website.

https://www.greenfacelabs.com/pbj-eu/

Thanks again for your comments. I want everything to be as good as it can be, but things do slip through the cracks. Just too many hats and not enough heads. 😉

Have you been able to get the needed parts?

Best,

Shannon

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

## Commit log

2020-11-12 Init checkin for ver 2.0
    [PBJ EU.kicad_pcb, PBJ EU.sch, PBJ EU_transistor.sch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]
2020-12-08 ver 3.0
    [PBJ EU.kicad_pcb, PBJ EU.sch, pbj_eu.xlsx]
2021-01-26 Removed unused KiCAD files.
    [PBJ EU_transistor.sch]
2021-01-26 Updates spice to match schematic values.
2021-12-25 Fixed rescue libs
    [PBJ EU.kicad_pcb, PBJ EU.sch, PBJ EU_parts.sch]
2021-12-25 Adds jpeg of schematic
2021-12-25 A little formatting of excel file.
    [pbj_eu.xlsx]
2021-12-25 Adds gerber files
    [PBJ EU-B_Cu.gbr, PBJ EU-B_Mask.gbr, PBJ EU-B_Paste.gbr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]
2021-12-25 Updates to ver 4.7.
    [PBJ EU-B_Cu.gbr, PBJ EU-B_Mask.gbr, PBJ EU-B_Paste.gbr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]
2022-01-27 version 4.8
    Fixes power connector.
    [PBJ EU-B_Cu.gbr, PBJ EU-B_Mask.gbr, PBJ EU-B_Paste.gbr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]
2022-01-28 v 4.9
    Adds caps to regulator. Adds graphics and text.
    [PBJ EU-B_Cu.gbr, PBJ EU-B_Mask.gbr, PBJ EU-B_Paste.gbr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]
2022-02-19 Move to KiCAD 6.0
    [PBJ EU-B_Cu.gbr, PBJ EU-B_Mask.gbr, PBJ EU-B_Paste.gbr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]
2022-02-19 Fixed 3d models
    Some 3d models are still unavailable
    [PBJ EU.kicad_pcb]
2022-02-19 Changed name so that BOM would work
    Looks like 6.0 BOM bombs when there is a space in the filename.
    [PBJ_EU-B_Cu.gbr, PBJ_EU-B_Mask.gbr, PBJ_EU-B_Paste.gbr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]
2022-02-19 Adds BOM
    [PBJ_EU.kicad_sch, PBJ_EU.xlsx, pbj_eu.xlsx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]
2022-02-22 Updates footprint 3d shapes
    [PBJ_EU.kicad_pcb]
2022-03-04 Adds pdf of schematic
2022-08-20 Version 4.10
    [PBJ_EU-B_Cu.gbr, PBJ_EU-B_Mask.gbr, PBJ_EU-B_Paste.gbr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]
2022-09-20 Adds note to schematic about 3.3V regulator option
    [PBJ_EU.kicad_sch, PBJ_EU.xlsx]
2022-11-12 v5.2
    Adds LCSC build support. Fixes to monitor circuitry.
    [PBJ_EU-B_Cu.gbr, PBJ_EU-B_Mask.gbr, PBJ_EU-B_Paste.gbr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]
2022-11-12 Update PBJ_EU.kicad_sch
    Testing branch
    [PBJ_EU.kicad_sch]
2022-11-15 lm317 experiment checkin
    [PBJ_EU-B_Cu.gbr, PBJ_EU-B_Mask.gbr, PBJ_EU-B_Paste.gbr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]
2022-11-16 Uses LM317 for regulators now.
    [PBJ_EU-B_Cu.gbr, PBJ_EU-B_Mask.gbr, PBJ_EU-B_Paste.gbr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]
